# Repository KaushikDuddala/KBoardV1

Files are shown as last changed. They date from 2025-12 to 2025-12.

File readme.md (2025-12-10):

# KBoard

The KBoard is a simple RP2040 devboard designed from the guide!! I made some changes visually like the orientation of the chip bc lowk 45 degrees looks cooler. routing was a nightmate tho!!

## Features:

- RP2040 microcontroller  
- USB-C connector for programming/power  
- Standard pin headers

## Future Features:

- Convert to a BadUSB design
- Wi-Fi/BT support  
- Battery Support?

## Final Design

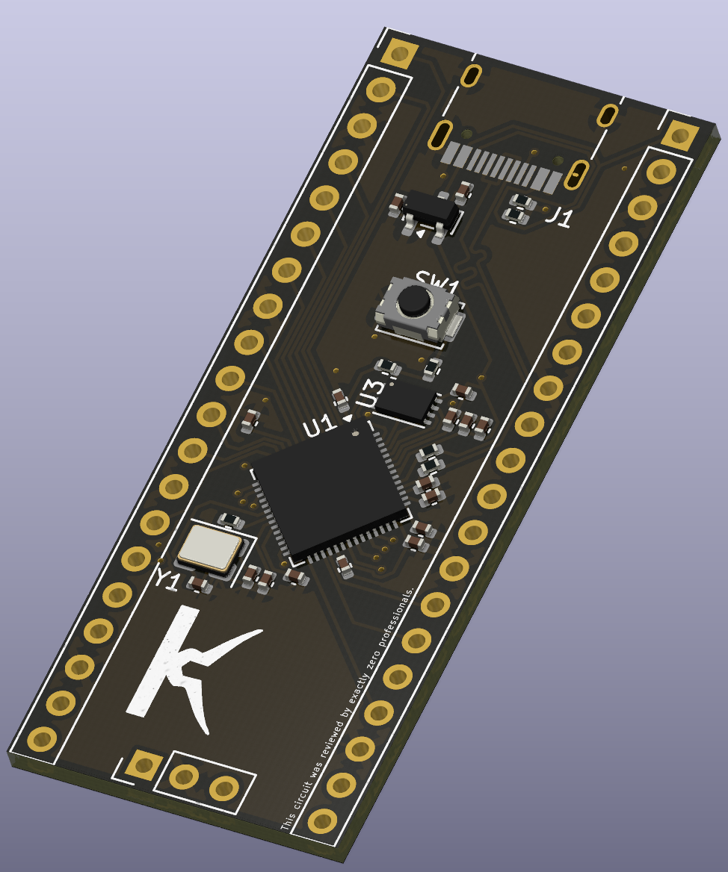
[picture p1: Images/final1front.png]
Front
  
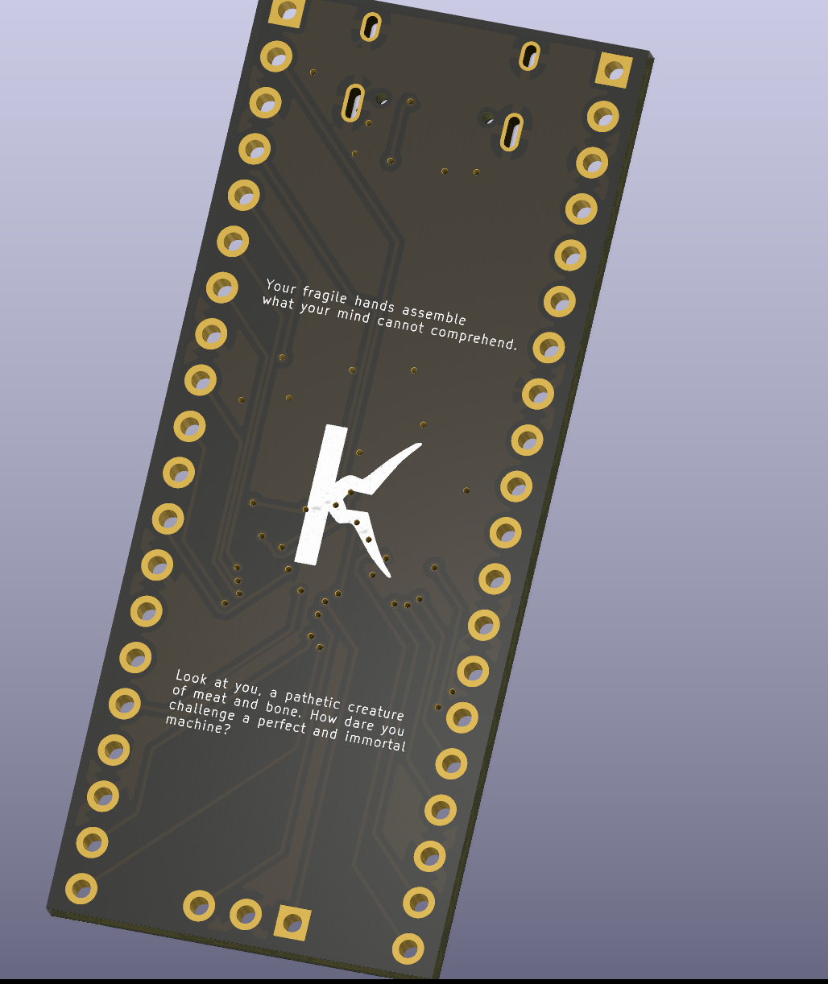
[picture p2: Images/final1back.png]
Back 1
  
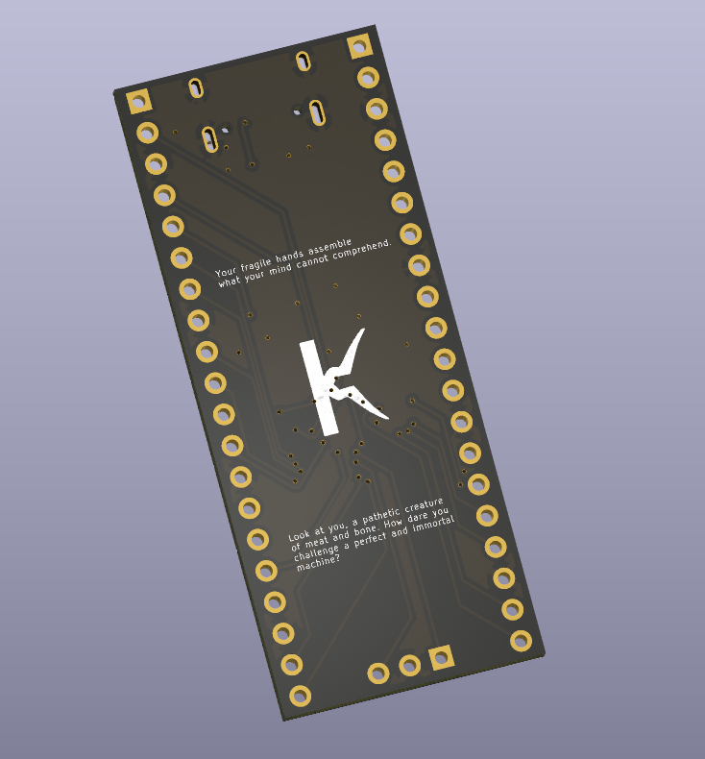
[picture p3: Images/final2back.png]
Back 2


## PCB Design

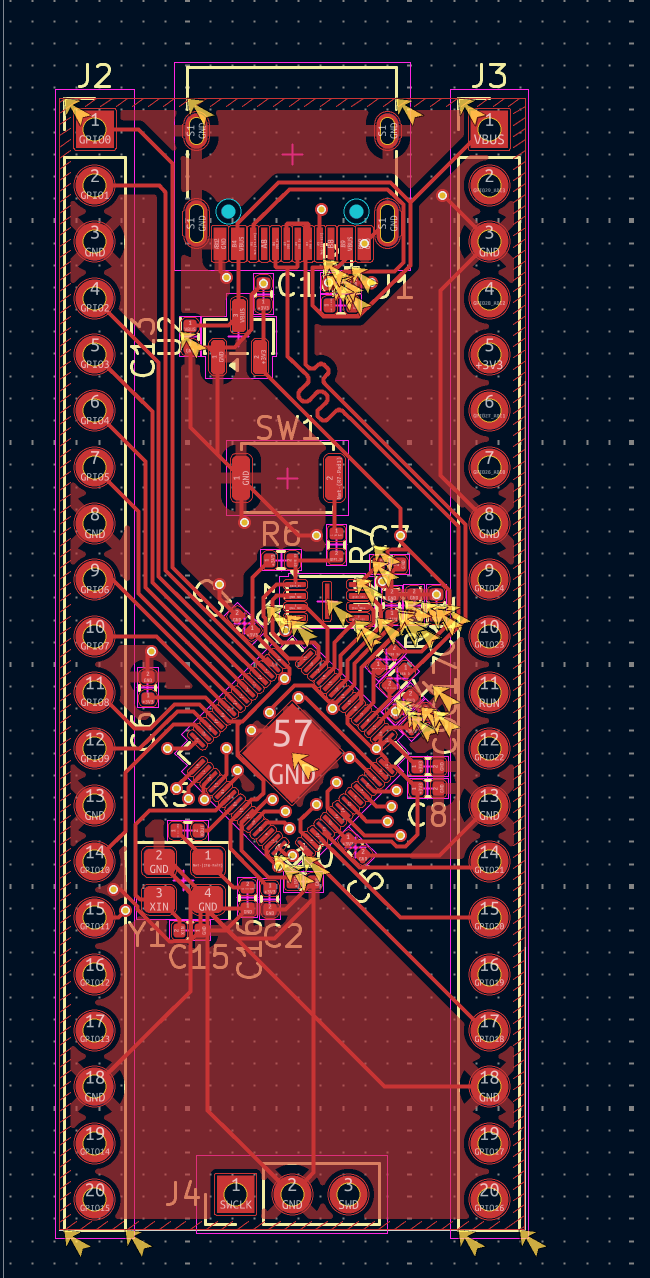
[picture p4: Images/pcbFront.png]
PCB Front
  
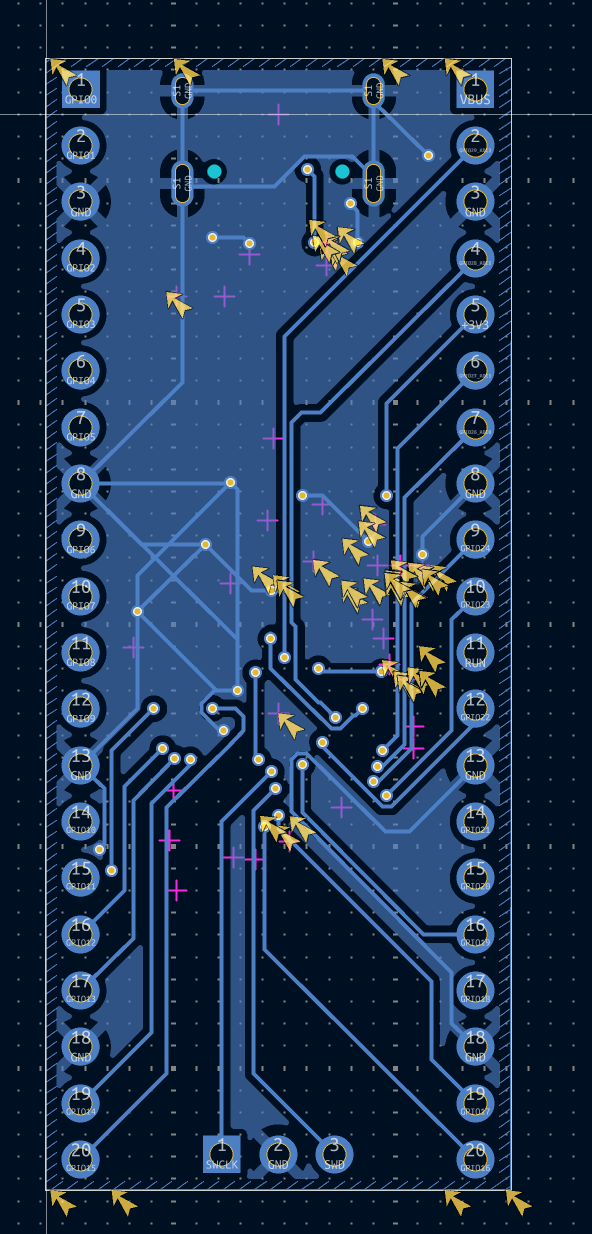
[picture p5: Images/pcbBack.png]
PCB Back
  
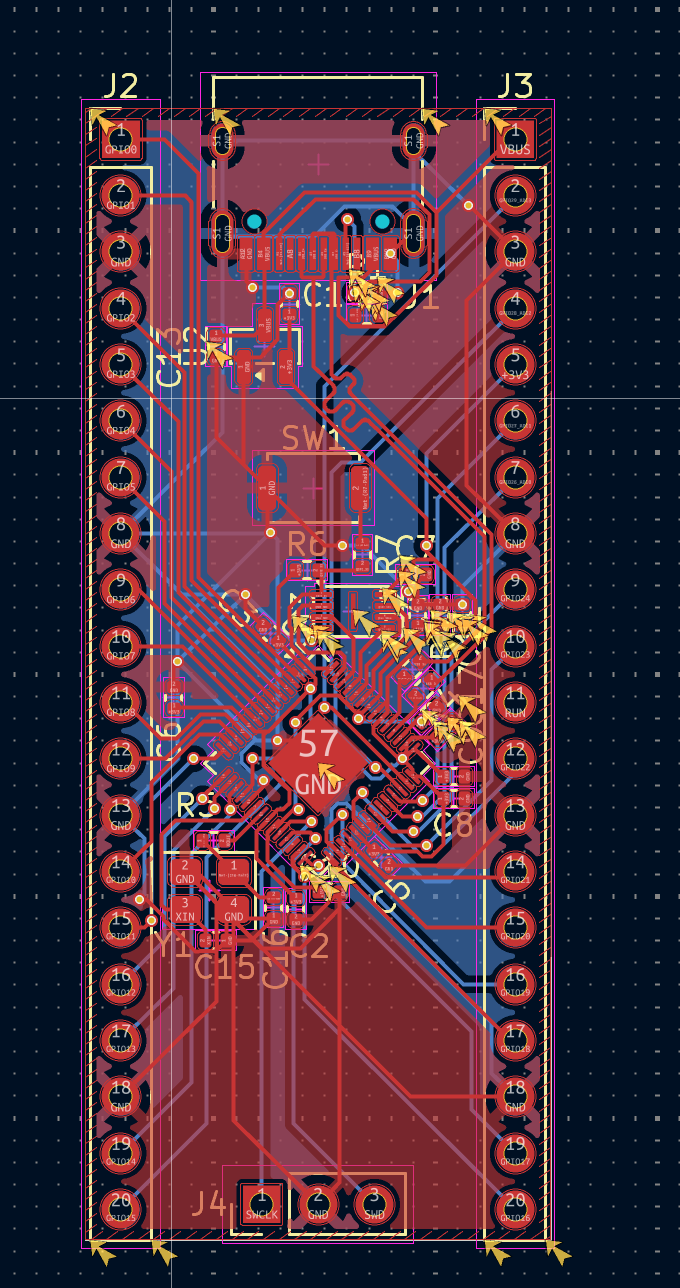
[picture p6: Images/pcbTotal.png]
PCB Total
  
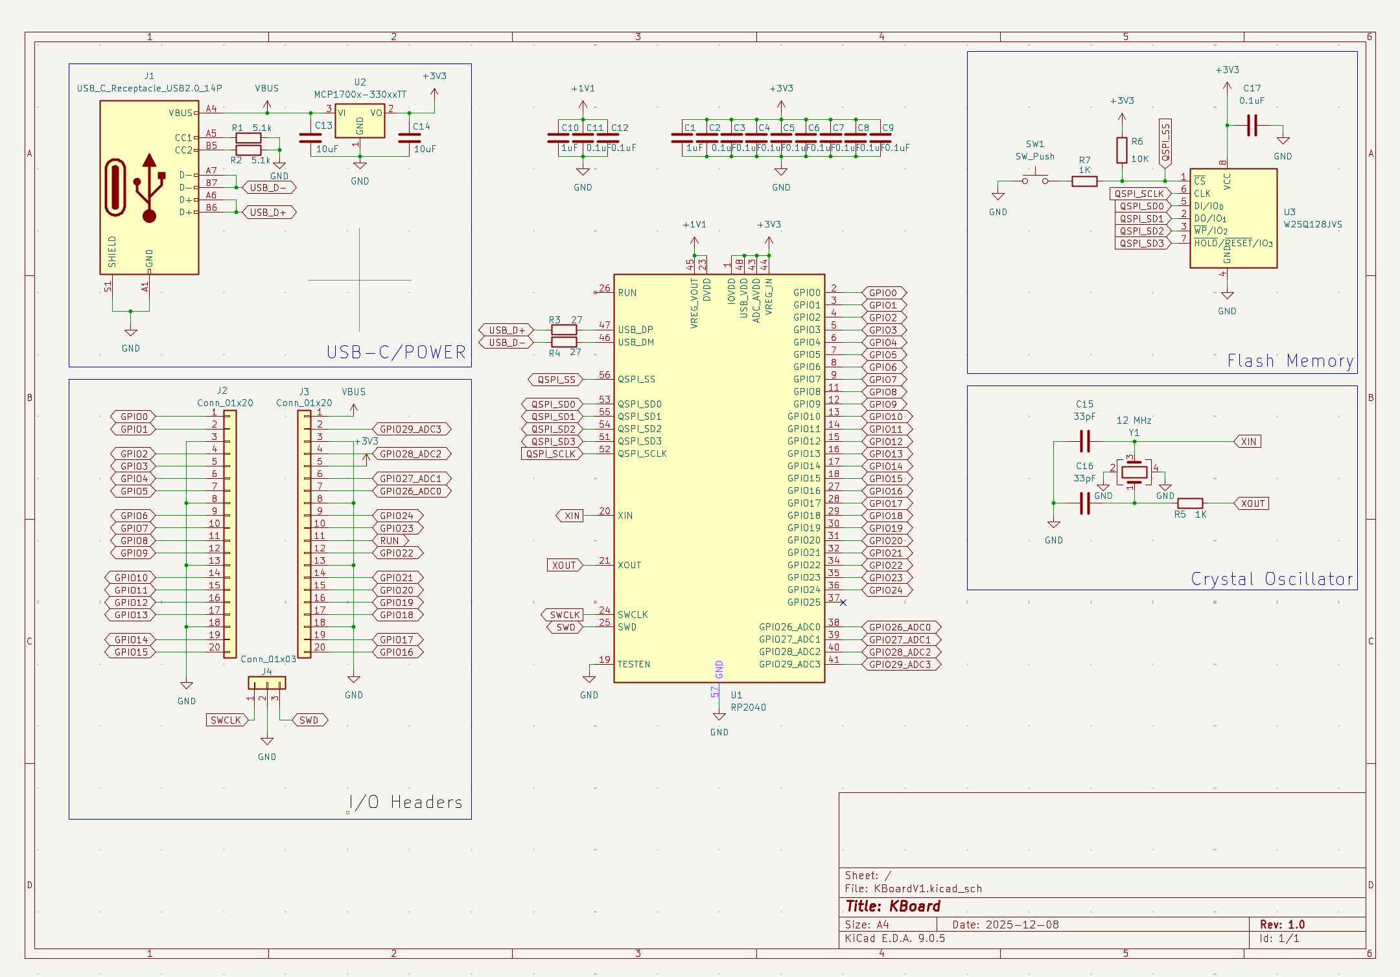
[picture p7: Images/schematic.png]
Schematic


## Bill of Materials (BOM)

A combined BOM including JLCPCB part numbers:

|Id|Designator|Footprint|Quantity|Designation|Supplier & Ref|JLCPCB Part #|Unit Price|
|--|---|---|---|---|---|---|---|
|1|J3,J2|PinHeader_1x20_P2.54mm_Vertical|2|Conn_01x20||| |
|2|U1|QFN-56-1EP_7x7mm_P0.4mm_EP3.2x3.2mm|1|RP2040||C2040|$1.8330|
|3|U3|Winbond_USON-8-1EP_3x2mm_P0.5mm_EP0.2x1.6mm|1|W25Q128JVS||C2843335|$1.1730|
|4|C8,C5,C2,C11,C17,C12,C9,C7,C6,C4,C3|C_0402_1005Metric|11|0.1uF||C1525|$0.0264|
|5|R5,R7|R_0402_1005Metric|2|1K||C11702|$0.0024|
|6|C16,C15|C_0402_1005Metric|2|33pF||C1562|$0.0040|
|7|Y1|Crystal_SMD_3225-4Pin_3.2x2.5mm|1|12 MHz||C9002|$0.1290|
|8|U2|SOT-23|1|MCP1700x-330xxTT||C39051|$1.9695|
|9|SW1|SW_Push_SPST_NO_Alps_SKRK|1|SW_Push||C720477|$0.0850|
|10|R6|R_0402_1005Metric|1|10K||C25744|$0.0010|
|11|R4,R3|R_0402_1005Metric|2|27||C25100|$0.0120|
|12|R2,R1|R_0402_1005Metric|2|5.1k||C25905|$0.0020|
|13|J4|PinHeader_1x03_P2.54mm_Vertical|1|Conn_01x03||| |
|14|C14,C13|C_0402_1005Metric|2|10uF||C19702|$0.0224|
|15|C10,C1|C_0402_1005Metric|2|1uF||C52923|$0.0116|
|16|J1|USB_C_Receptacle_HRO_TYPE-C-31-M-12|1|USB_C_Receptacle_USB2.0_14P||C165948|$0.3388|

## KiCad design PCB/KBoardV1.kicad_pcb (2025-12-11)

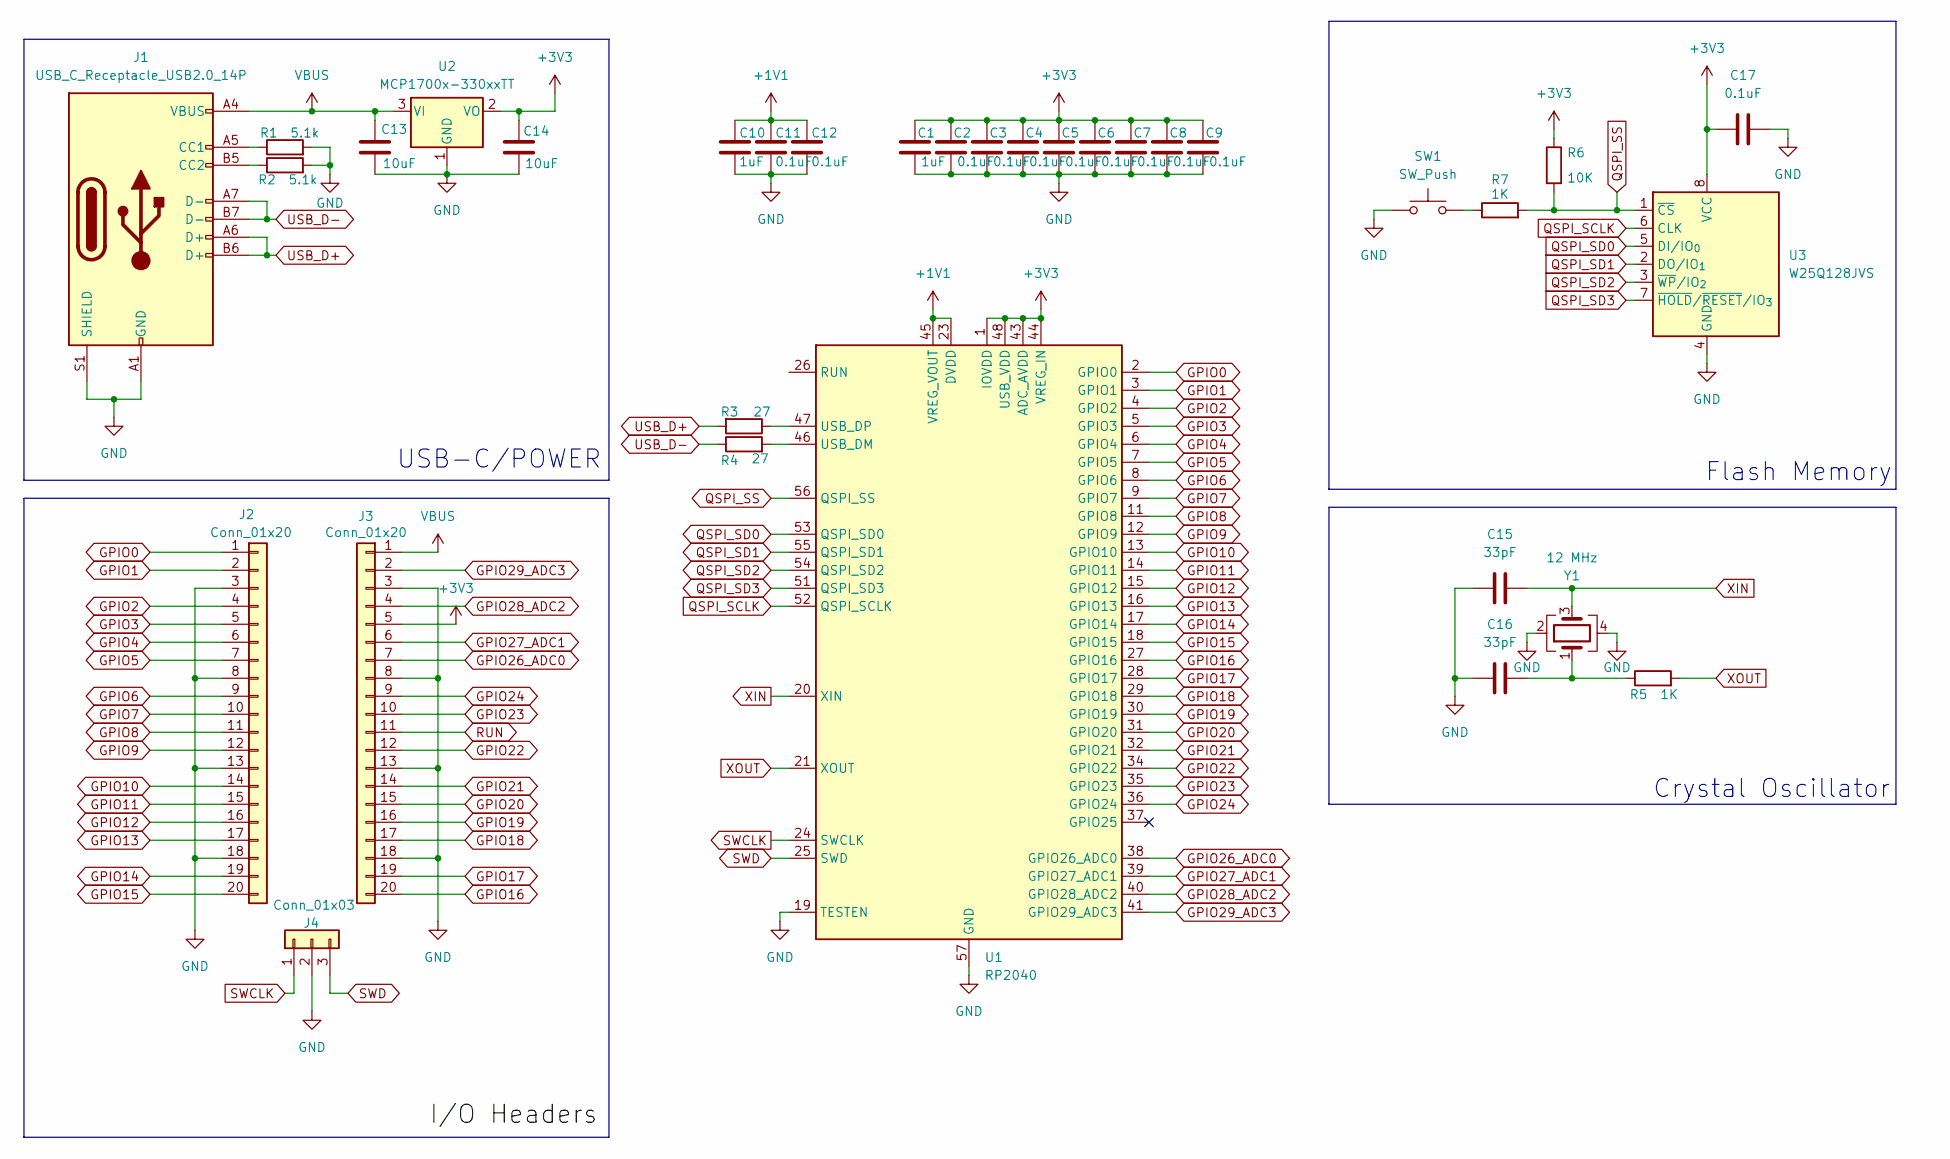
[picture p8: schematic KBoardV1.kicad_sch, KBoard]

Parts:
C1, C10: 1uF; C_0402_1005Metric
C2, C3, C4, C5, C6, C7, C8, C9, C11, C12, C17: 0.1uF; C_0402_1005Metric
C13, C14: 10uF; C_0402_1005Metric
C15, C16: 33pF; C_0402_1005Metric
J1: USB_C_Receptacle_USB2.0_14P; USB_C_Receptacle_HRO_TYPE-C-31-M-12
J2, J3: Conn_01x20; PinHeader_1x20_P2.54mm_Vertical
J4: Conn_01x03; PinHeader_1x03_P2.54mm_Vertical
R1, R2: 5.1k; R_0402_1005Metric
R3, R4: 27; R_0402_1005Metric
R5, R7: 1K; R_0402_1005Metric
R6: 10K; R_0402_1005Metric
SW1: SW_Push; SW_Push_SPST_NO_Alps_SKRK
U1: RP2040; QFN-56-1EP_7x7mm_P0.4mm_EP3.2x3.2mm
U2: MCP1700x-330xxTT; SOT-23
U3: W25Q128JVS; Winbond_USON-8-1EP_3x2mm_P0.5mm_EP0.2x1.6mm
Y1: 12 MHz; Crystal_SMD_3225-4Pin_3.2x2.5mm

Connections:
+1V1: C10.1, C11.1, C12.1, U1.23 (DVDD), U1.45 (VREG_VOUT), U1.50 (DVDD)
+3V3: C1.1, C2.1, C3.1, C4.1, C5.1, C6.1, C7.1, C8.1, C9.1, C14.1, C17.1, J3.5, R6.1, U1.1 (IOVDD), U1.10 (IOVDD), U1.22 (IOVDD), U1.33 (IOVDD), U1.42 (IOVDD), U1.43 (ADC_AVDD), U1.44 (VREG_IN), U1.48 (USB_VDD), U1.49 (IOVDD), U2.2 (VO), U3.8 (VCC)
GND: C1.2, C2.2, C3.2, C4.2, C5.2, C6.2, C7.2, C8.2, C9.2, C10.2, C11.2, C12.2, C13.2, C14.2, C15.1, C16.1, C17.2, J1.A1 (GND), J1.A12 (GND), J1.B1 (GND), J1.B12 (GND), J1.S1 (SHIELD), J2.3, J2.8, J2.13, J2.18, J3.3, J3.8, J3.13, J3.18, J4.2, R1.2, R2.2, SW1.1, U1.19 (TESTEN), U1.57 (GND), U2.1 (GND), U3.4 (GND), Y1.2, Y1.4
GPIO0: J2.1, U1.2 (GPIO0)
GPIO1: J2.2, U1.3 (GPIO1)
GPIO2: J2.4, U1.4 (GPIO2)
GPIO3: J2.5, U1.5 (GPIO3)
GPIO4: J2.6, U1.6 (GPIO4)
GPIO5: J2.7, U1.7 (GPIO5)
GPIO6: J2.9, U1.8 (GPIO6)
GPIO7: J2.10, U1.9 (GPIO7)
GPIO8: J2.11, U1.11 (GPIO8)
GPIO9: J2.12, U1.12 (GPIO9)
GPIO10: J2.14, U1.13 (GPIO10)
GPIO11: J2.15, U1.14 (GPIO11)
GPIO12: J2.16, U1.15 (GPIO12)
GPIO13: J2.17, U1.16 (GPIO13)
GPIO14: J2.19, U1.17 (GPIO14)
GPIO15: J2.20, U1.18 (GPIO15)
GPIO16: J3.20, U1.27 (GPIO16)
GPIO17: J3.19, U1.28 (GPIO17)
GPIO18: J3.17, U1.29 (GPIO18)
GPIO19: J3.16, U1.30 (GPIO19)
GPIO20: J3.15, U1.31 (GPIO20)
GPIO21: J3.14, U1.32 (GPIO21)
GPIO22: J3.12, U1.34 (GPIO22)
GPIO23: J3.10, U1.35 (GPIO23)
GPIO24: J3.9, U1.36 (GPIO24)
GPIO26_ADC0: J3.7, U1.38 (GPIO26_ADC0)
GPIO27_ADC1: J3.6, U1.39 (GPIO27_ADC1)
GPIO28_ADC2: J3.4, U1.40 (GPIO28_ADC2)
GPIO29_ADC3: J3.2, U1.41 (GPIO29_ADC3)
unnamed: C16.2, R5.1, Y1.1
unnamed: J1.A5 (CC1), R1.1
unnamed: J1.B5 (CC2), R2.1
unnamed: R7.1, SW1.2
unnamed: R4.2, U1.46 (USB_DM)
unnamed: R3.1, U1.47 (USB_DP)
QSPI_SCLK: U1.52 (QSPI_SCLK), U3.6 (CLK)
QSPI_SD0: U1.53 (QSPI_SD0), U3.5 (DI/IO_{0})
QSPI_SD1: U1.55 (QSPI_SD1), U3.2 (DO/IO_{1})
QSPI_SD2: U1.54 (QSPI_SD2), U3.3 (~WP/IO_{2})
QSPI_SD3: U1.51 (QSPI_SD3), U3.7 (~HOLD/~RESET/IO_{3})
QSPI_SS: R6.2, R7.2, U1.56 (QSPI_SS), U3.1 (~CS)
RUN: J3.11
SWCLK: J4.1, U1.24 (SWCLK)
SWD: J4.3, U1.25 (SWD)
USB_D+: J1.A6 (D+), J1.B6 (D+), R3.2
USB_D-: J1.A7 (D-), J1.B7 (D-), R4.1
VBUS: C13.1, J1.A4 (VBUS), J1.A9 (VBUS), J1.B4 (VBUS), J1.B9 (VBUS), J3.1, U2.3 (VI)
XIN: C15.2, U1.20 (XIN), Y1.3
XOUT: R5.2, U1.21 (XOUT)

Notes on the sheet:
USB-C/POWER
Crystal Oscillator
Flash Memory

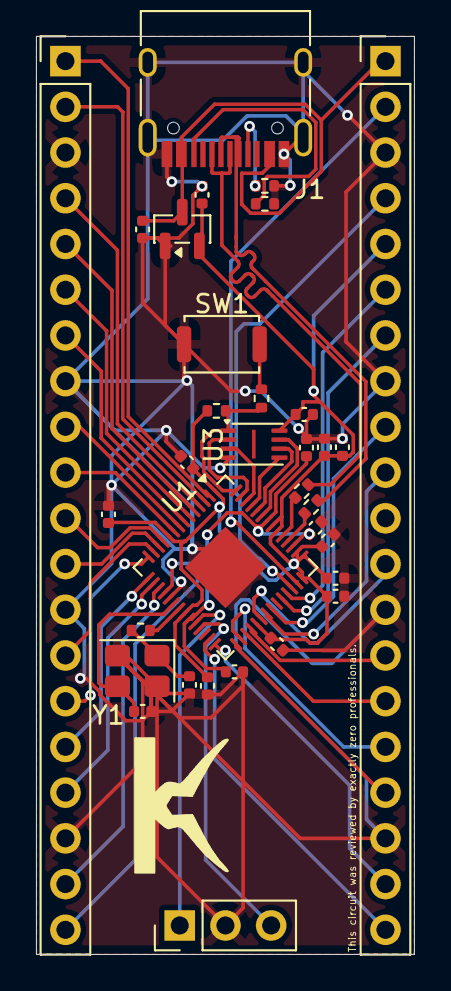
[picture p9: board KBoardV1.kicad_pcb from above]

Board: 2 copper layers, 21.0 x 51.0 mm, 33 parts (0 on the bottom side), 51 nets.
